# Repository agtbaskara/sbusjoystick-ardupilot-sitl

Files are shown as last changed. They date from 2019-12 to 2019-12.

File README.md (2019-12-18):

# SBUS to USB Joystick Converter with Ardupilot SITL Support

## Requirement
- PC with Linux OS (Tested on Ubuntu 18.04)
- RC Transmitter (Tested on Frsky Taranis QX7)
- SBUS RC Receiver (Tested on Frsky X8R and FX400R)
- Arduino Pro Micro (or another ATmega32U4 based Arduino)
- SBUS Inverter (DIY Schematic and PCB design file in repository)

## Setup Instruction
- Install Arduino Joystick Library library (https://github.com/MHeironimus/ArduinoJoystickLibrary)
- Install this fork of FUTABA_SBUS library (https://github.com/agtbaskara/FUTABA_SBUS)
- Upload `sbusjoystick-ardupilot-sitl.ino` to Arduino
- (Optional) for Ardupilot SITL support copy `sbusjoystick.yml` to `~/.local/lib/python2.7/site-packages/MAVProxy/modules/mavproxy_joystick/joysticks`

## Button Mapping:
- Axis 0: Channel 0
- Axis 1: Channel 1
- Axis 2: Channel 10
- Axis 3: Channel 2
- Axis 4: Channel 3
- Axis 5: Channel 11
- Button 0: Channel 4 Low
- Button 1: Channel 4 Mid
- Button 2: Channel 4 High
- Button 3: Channel 5 Low
- Button 4: Channel 5 Mid
- Button 5: Channel 5 High
- Button 6: Channel 6 Low
- Button 7: Channel 6 Mid
- Button 8: Channel 6 High
- Button 9: Channel 7 Low
- Button 10: Channel 7 Mid
- Button 11: Channel 7 High
- Button 12: Channel 8 Low
- Button 13: Channel 8 High
- Button 14: Channel 9 Low
- Button 15: Channel 9 High

## To Do
- Add PPM RC Receiver Support

## Reference
- Source code based on https://github.com/Robinhuett/sbuscontroller, https://github.com/mikeshub/FUTABA_SBUS, and https://github.com/MHeironimus/ArduinoJoystickLibrary
- Hardware design based on https://oscarliang.com/diy-sbus-usb-converter/
- Configuration based on https://github.com/ArduPilot/MAVProxy/blob/master/docs/JOYSTICKS.md

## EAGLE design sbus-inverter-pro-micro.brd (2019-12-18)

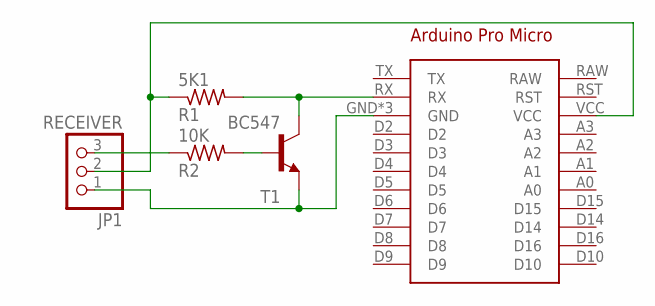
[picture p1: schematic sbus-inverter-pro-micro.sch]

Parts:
ARDUINO1: ARDUINO_PRO_MICRO
JP1: RECEIVER; 1X03/90
R1: 5K1; 0207/10
R2: 10K; 0207/10
T1: BC547; TO92

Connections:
unnamed: R2.2, T1.2 (B)
unnamed: ARDUINO1.GND, ARDUINO1.GND@1 (GND), ARDUINO1.GND@2 (GND), JP1.1, T1.1 (E)
unnamed: ARDUINO1.RX, R1.2, T1.3 (C)
unnamed: JP1.3, R2.1
unnamed: ARDUINO1.VCC, JP1.2, R1.1

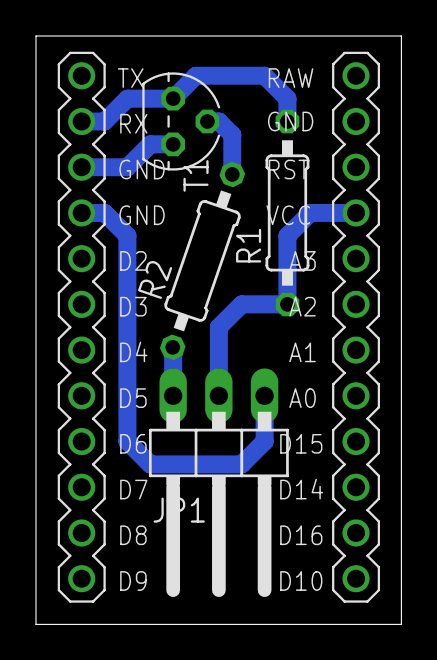
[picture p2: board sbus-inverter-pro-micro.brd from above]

Board: 2 copper layers, 20.3 x 32.7 mm, 5 parts (0 on the bottom side), 5 nets.

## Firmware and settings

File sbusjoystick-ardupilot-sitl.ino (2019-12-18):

#include "Joystick.h"
#include "FUTABA_SBUS.h"

Joystick_ Joystick;
FUTABA_SBUS sbus;

uint16_t channels[12];

void setup() {
  Joystick.setXAxisRange(172, 1811);
  Joystick.setYAxisRange(172, 1811);
  Joystick.setRxAxisRange(172, 1811);
  Joystick.setRyAxisRange(172, 1811);
  Joystick.setZAxisRange(172, 1811);
  Joystick.setRzAxisRange(172, 1811);

  sbus.begin();

  Joystick.begin(false);
}

void loop() {
  sbus.FeedLine();
  if (sbus.toChannels == 1) {
    sbus.UpdateServos();
    sbus.UpdateChannels();
    sbus.toChannels = 0;

    channels[0] = sbus.channels[0];
    channels[1] = sbus.channels[1];
    channels[2] = sbus.channels[2];
    channels[3] = sbus.channels[3];
    channels[4] = sbus.channels[4];
    channels[5] = sbus.channels[5];
    channels[6] = sbus.channels[6];
    channels[7] = sbus.channels[7];
    channels[8] = sbus.channels[8];
    channels[9] = sbus.channels[9];
    channels[10] = sbus.channels[10];
    channels[11] = sbus.channels[11];
  }

  Joystick.setXAxis(channels[0]);
  Joystick.setYAxis(channels[1]);
  Joystick.setRxAxis(channels[2]);
  Joystick.setRyAxis(channels[3]);

  Joystick.setButton(0, channels[4] <= 982);
  Joystick.setButton(1, channels[4] > 982 && channels[4] < 1002);
  Joystick.setButton(2, channels[4] >= 1002);

  Joystick.setButton(3, channels[5] <= 982);
  Joystick.setButton(4, channels[5] > 982 && channels[5] < 1002);
  Joystick.setButton(5, channels[5] >= 1002);

  Joystick.setButton(6, channels[6] <= 982);
  Joystick.setButton(7, channels[6] > 982 && channels[6] < 1002);
  Joystick.setButton(8, channels[6] >= 1002);

  Joystick.setButton(9, channels[7] <= 982);
  Joystick.setButton(10, channels[7] > 982 && channels[7] < 1002);
  Joystick.setButton(11, channels[7] >= 1002);

  Joystick.setButton(12, channels[8] <= 982);
  Joystick.setButton(13, channels[8] >= 1002);

  Joystick.setButton(14 ,channels[9] <= 982);
  Joystick.setButton(15 ,channels[9] >= 1002);

  Joystick.setZAxis(channels[10]);
  Joystick.setRzAxis(channels[11]);
  
  Joystick.sendState();
}
